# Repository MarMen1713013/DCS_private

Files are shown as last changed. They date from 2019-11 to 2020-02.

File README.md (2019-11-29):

# Estimate of an *unknown* torque and *constant reference* tracking 

## DONE
$$
I_{sens}/I_{out} = K = \textit{mean on datasheet}
$$

- [ ] Andrea: Motor parameter estimation
- [ ] Adrija: Torque estimation
- [ ] Marco: Hardware + P~~ID~~ (.ino or .m)

## Introduction

## Definition

## Goal

## Code

## Results

[TOC]

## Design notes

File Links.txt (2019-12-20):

1) Usefull Tutorial

https://howtomechatronics.com/tutorials/arduino/arduino-dc-motor-control-tutorial-l298n-pwm-h-bridge/ 

------------------------------------------------------------------------------------------------------

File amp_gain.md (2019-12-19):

# OP AMP configurations

Two choices are actually available:
1. transimpedance (low gain) + high voltage gain
2. transimpedance (high gain)

## First

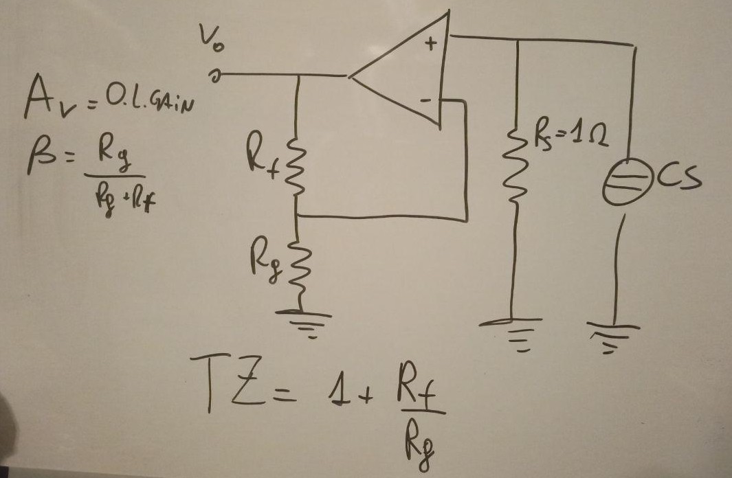
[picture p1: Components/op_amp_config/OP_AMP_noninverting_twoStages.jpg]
two_stages

$$
\left\{
\begin{align*}
V_o &= A_v*V_{in} \\
V_{in}^+ &= R_s*I_{cs} \\ 
V_{in}^- &= \frac{R_g}{R_f + R_g}*V_o
\end{align*}
\right.
$$
Setting $R_s = 1 \Omega$ we can exchange $V_{in}^+$ with $I_{cs}$, and easily solve the system.transimpedance
Or else we could see it in a __*Control fashion*__:
$$
\left\{
\begin{align*}
A_v &= \text{open loop gain} \\
\beta &= \frac{R_g}{R_f + R_g}= \text{feedback transfer function} \\
G &= R_s = \text{pre-amplifier}
\end{align*}
\right.
$$
Hence: $W_{TZ} = G \frac{A_v}{1+\beta A_v} \simeq \frac{G}{\beta} = 1+\frac{R_f}{R_g}$ is our Voltage gain.

## Second

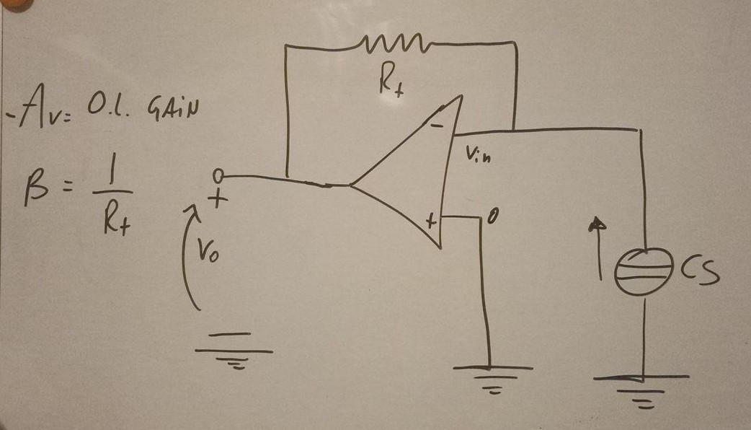
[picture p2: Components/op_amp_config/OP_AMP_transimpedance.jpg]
transimpedance

$$
\left\{
\begin{align*}
V_{in}^+ &= 0 \\
V_{in}^- &= V_{in} =V_o + R_sI_{cs} \\
V_o &= -A_vV_{in}
\end{align*}
\right.
$$
It could be solved easily or else, as before, we could see it in a __*Control fashion*__:
$$
\left\{
\begin{align*}
-A_v &= \text{open loop gain} \\
\beta &= \frac{1}{R_f}= \text{feedback transfer function}
\end{align*}
\right.
$$
Hence: $W_{TZ} = \frac{-A_v}{1-\beta A_v} = \frac{1}{\frac{1}{-A_v}+\beta}\simeq \frac{1}{\beta} = R_f$ is our Voltage gain.

### Anti Aliasing

Since an anti-aliasing is needed on the current loop, we simply implement it as low pass filter, i.e. we add a capacitor $C_f$ in parallel to the resistance $R_f$ so as the total transfer functions $\beta$ and $W_{TZ}$ are:
$$
\begin{align*}
\beta &= \frac{1}{R_f} + sC_{f}\\
W_{tz} &\simeq \frac{1}{\beta} = \frac{R_f}{1+sC_fR_f}
\end{align*}
$$
Imposing the time constant to be at $\tau = \frac{1}{1kHz} = R_fC_f$ we have $C_f$ as :
$$
C_f = \frac{1}{R_f*1kHz}
$$

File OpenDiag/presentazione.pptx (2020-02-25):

## Estimation of DC Motor Load

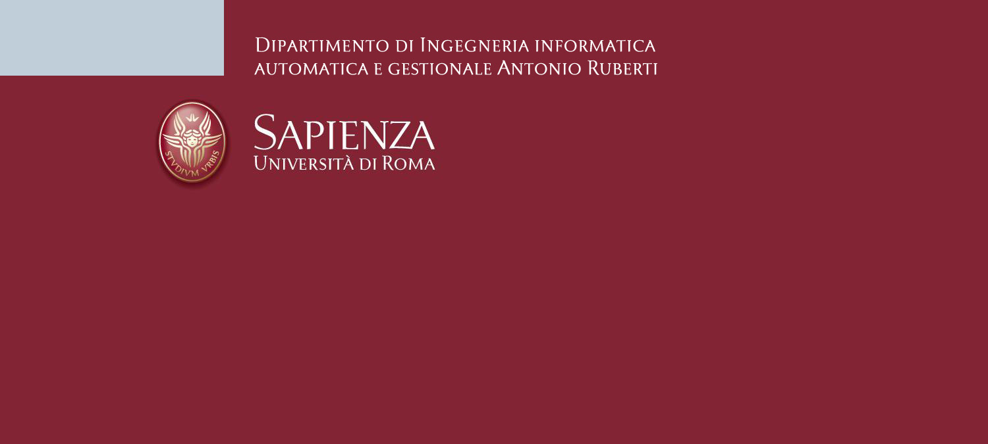
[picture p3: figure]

Project Members: Marco Menchetti, Adrija Sen, Andrea Malaguti

Guided By: Prof. Claudia Califano
Course: Digital Systems Control

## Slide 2

Estimation of DC Motor Load

Goal of the project :

- Estimation of DC Motor parameters
- Estimation of DC Motor load
- Realisation of a PI Controller

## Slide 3

HARDWARE AND SOFTWARE USED:

- Arduino Uno R3
- DC Motor (2x12V)
- H-Bridge(LM298-N)
- Hall-Effect Encoder
- Operational Amplifier(LM324N)
- Resistors()
- Potentiometer 1KΩ
- Power Supply – (12V, 2A max.)
- Matlab 2019a
- Matlab Arduino support package

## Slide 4

Arduino UNO R3

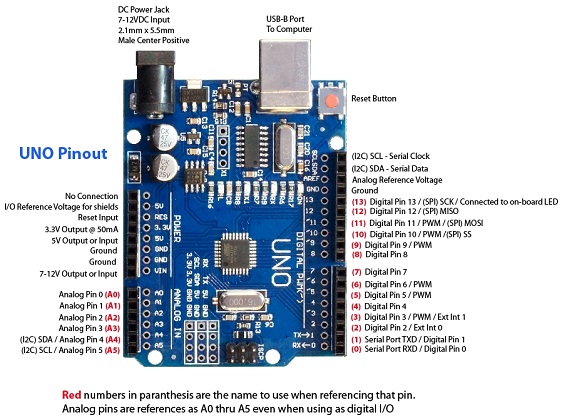
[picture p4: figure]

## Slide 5

Arduino Uno is a microcontroller board based on the ATmega328P (datasheet). It has 14 digital input/output pins (of which 6 can be used as PWM outputs), 6 analog inputs, a 16 MHz quartz crystal.

Tech Specifications of Arduino UNO R3:

Operating Voltage | 5V
Input Voltage (recommended) | 7-12V
Input Voltage (limit) | 6-20V
Digital I/O Pins | 14 (of which 6 provide PWM output)
PWM Digital I/O Pins | 6
Analog Input Pins | 6
DC Current per I/O Pin | 20 mA
DC Current for 3.3V Pin | 50 mA
Flash Memory | 32 KB (ATmega328P) of which 0.5 KB used by bootloader
SRAM | 2 KB (ATmega328P)
EEPROM | 1 KB (ATmega328P)
Clock Speed | 16 MHz
LED_BUILTIN | 13

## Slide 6

DC Motor + Encoder

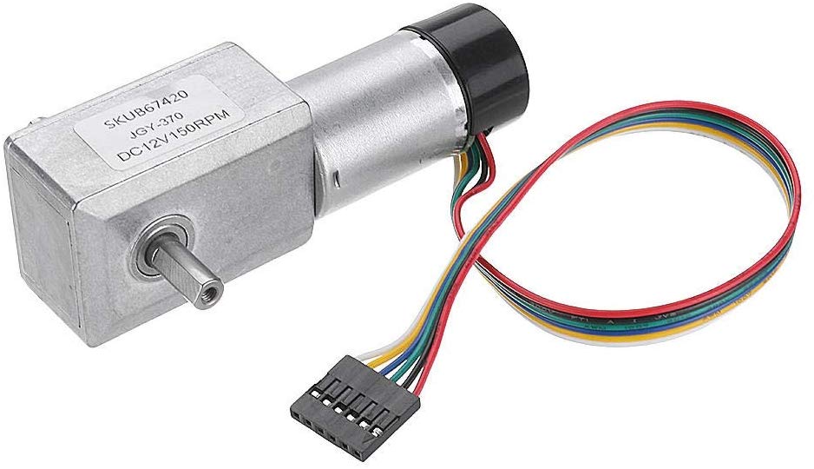
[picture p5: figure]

## TECHNICAL SPECIFICATIONS FOR ENCODER-MOTOR DUO

- Operating voltage: 6V to 18V
- Rated voltage: 12V
- Reduction ratio: 40:1
- No-load current: 40 mA
- No-load speed: 150 RPM
- Rated torque: 1.5 kg cm
- Maximum torque: 6.4 kg cm
- Stop current: 1.3 A
- Hall Incremental Encoder
- Encoder resolution: 440 CPR
- Weight: 150 g
- Red: Motor power +
- Black: Encoder GND
- Green: Encoder Phase A
- Yellow: Encoder Phase B
- Blue: Encoder power supply 5V
- White: Motor power

## LM324N (OPERATIONAL AMPLIFIER)

Slew Rate | 0.5V/µs
Gain Bandwidth Product | 1,2MHz
Current - Input Bias | 20nA
Voltage - Input Offset | 3mV
Current - Supply | 1.4mA
Current - Output / Channel | 40mA
Voltage - Supply, Single/Dual (±) | 3V ~ 32V, ±1.5V ~ 16V
Operating Temperature | 0°C ~ 70°C

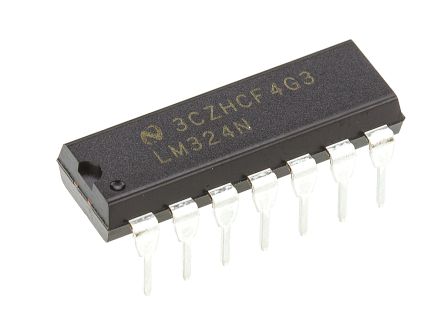
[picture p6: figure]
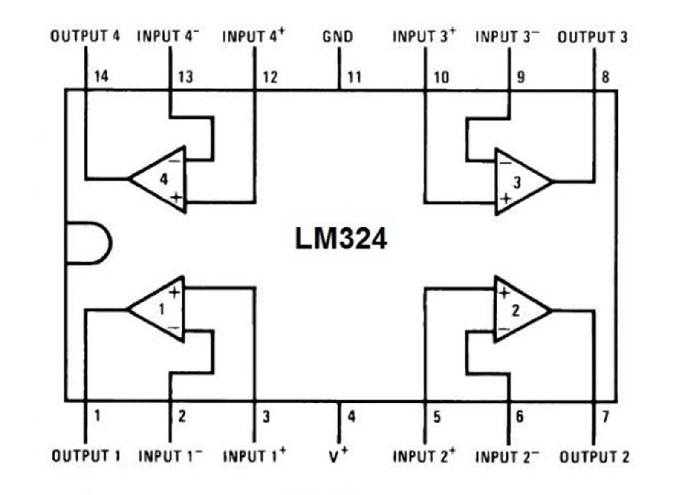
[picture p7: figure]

Pin-out for LM324N

## LM324N-NON-INVERTING AMPLIFIER

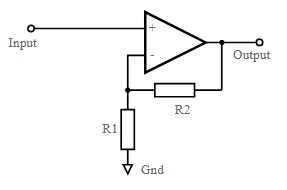
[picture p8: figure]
Non-Inverting Operational Amplifier Circuit

The gain of the non-inverting op-amp is calculated as:

We took the value of the resistors as :
R2= 1000 Ω
R1= 1000 Ω
Therefore, the gain Av= 2

## L298N (H-BRIDGE DRIVER)

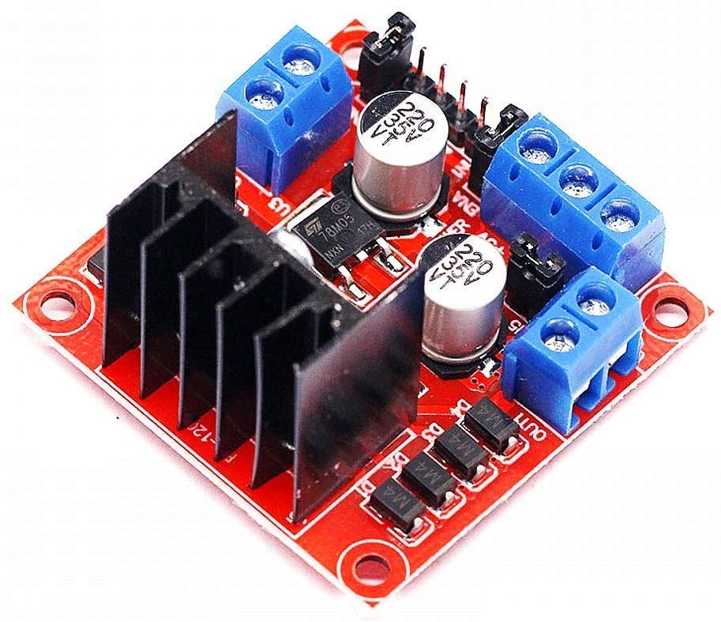
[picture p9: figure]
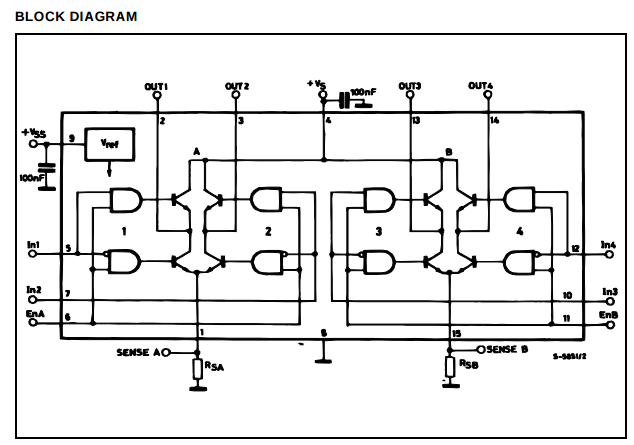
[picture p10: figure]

## L298N (TECHNICAL SPECIFICATIONS )

Technical
Bandwidth | 1 MHz
Common Mode Rejection Ratio | 70 dB
Dual Supply Voltage | 9 V
Gain | 100 dB
Gain Bandwidth Product | 1.3 MHz
Input Bias Current | 150 nA
Input Offset Voltage (Vos) | 7 mV
Max Dual Supply Voltage | 15 V
Max Operating Temperature | 70 °C
Max Supply Voltage | 30 V
Min Dual Supply Voltage | 1.5 V
Min Operating Temperature | 0 °C
Min Supply Voltage | 3 V
Nominal Supply Current | 1.2 mA
Number of Amplifiers | 4
Number of Channels | 4
Number of Circuits | 4
Number of Elements | 4
Operating Supply Current | 1.5 mA
Operating Supply Voltage | 15 V
Output Current | 70 mA
Output Current per Channel | 70 mA
Slew Rate | 0.4 V/µs
Voltage Gain | 100 dB

## PULSE WIDTH MODULATION

Pulse Width Modulation(PWM) allows us to vary how much time the signal is high in an analog fashion. While the signal can only be high (usually 5V) or low (ground) at any time, we can change the proportion of time the signal is high compared to when it is low over a consistent time interval.

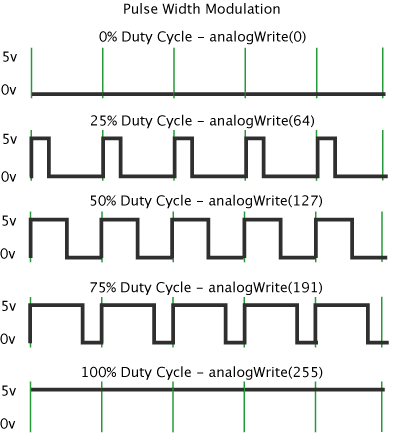
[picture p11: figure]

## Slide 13

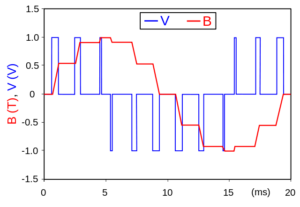
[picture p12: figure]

Sample output of PWM modulated signal

Duty Cycle is given by:

d= (t_(on))/(t_(on) +t_(off))

Type equation here.

## INCREMENTAL ENCODERS

An incremental encoder generates a pulse for each incremental step in it's rotation. The most common type of incremental encoder uses two output channels (A and B) to sense position. Using two code tracks with sectors positioned 90° out of phase, the two output channels of the quadrature encoder indicate both position and direction of rotation. If A leads B, for example, the disk is rotating in a clockwise direction else vice versa.

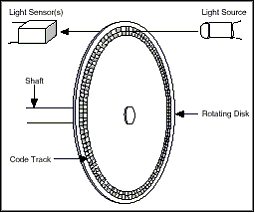
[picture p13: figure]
principles of an optical incremental encoder for position measurement

## Motor Parameters Estimation

J(dω)/(dt)+Bω=T−T_L
V_s =E_(emf) −R_a i_a

Since,

ω: rated speed
J: motor inertia
B: friction
Ra: armature resistance
ia: armature current
Eemf: back-ElectroMotiveForce

E_(emf) =K_e ω

V_s =K_e ω−R_a i_a

Therefore,

K_e =(V_s −R_a i_a)/ω

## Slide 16

Where, Vs= 12 V
ia = 40 mA (rated)
Ra= 13.7 Ω (estimated)
ω = 150 RPM = 15,7 rad/s

Back-EMF constant and Torque constant have the same numerical value for DC motors:

K_e [V/(rad/s)]=K_T [(Nm)/A]

So,
K_T =0.729[(Nm)/A]

&

K_e =0.729[V/(rad/s)]

## MECHANICAL TIME CONSTANT ESTIMATION

Mechanical time constant:
Time needed by the angular velocity to reach 63% of final value.

τ_(mech) =30ms

Now using, τ_(mech) = (R_(aJ))/(K_e K_T) [ms]

J=(K_e K_T τ_(mech))/(R_a)[kg/m^2 ]

Gives us,

J=13.4x 10^(−2) [kg/m^2 ]

## LOAD TORQUE ESTIMATION

J(dω)/(dt)+Bω=T−T_L
V_s =E_(emf) −R_a i_a

Inserting B=0, we get,
J(dω)/(dt)=T−T_L

Also at steady state, J(dω)/(dt) =0. Therefore, T−T_L =0.

This gives, T=T_L .

We know , T =K_T i_a

Torque-Current relationship

## MATLAB CODES FOR PI-CONTROLLER

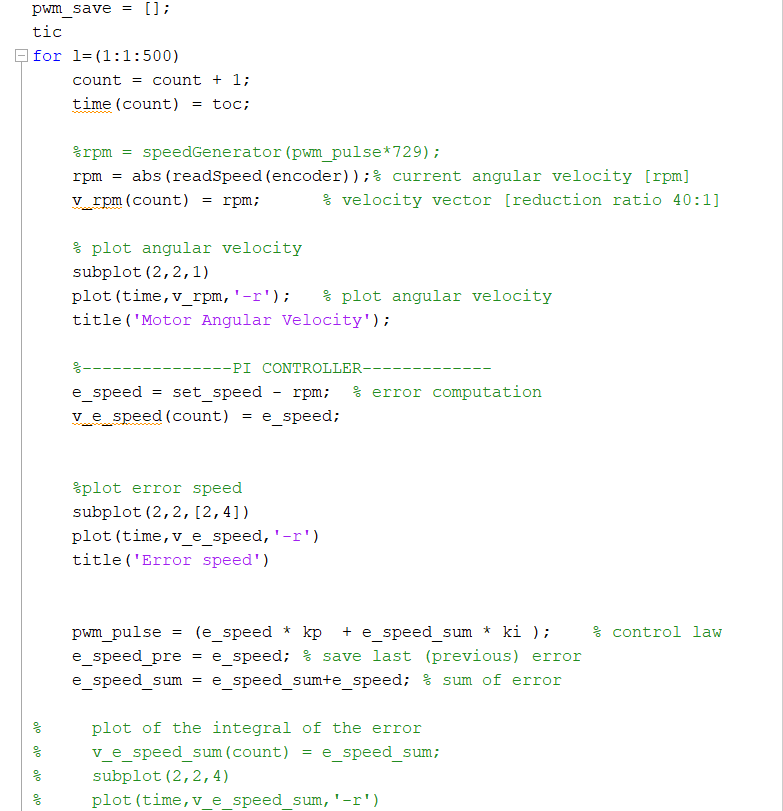
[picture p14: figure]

## MATLAB CODES FOR PI-CONTROLLER(CONTD.)

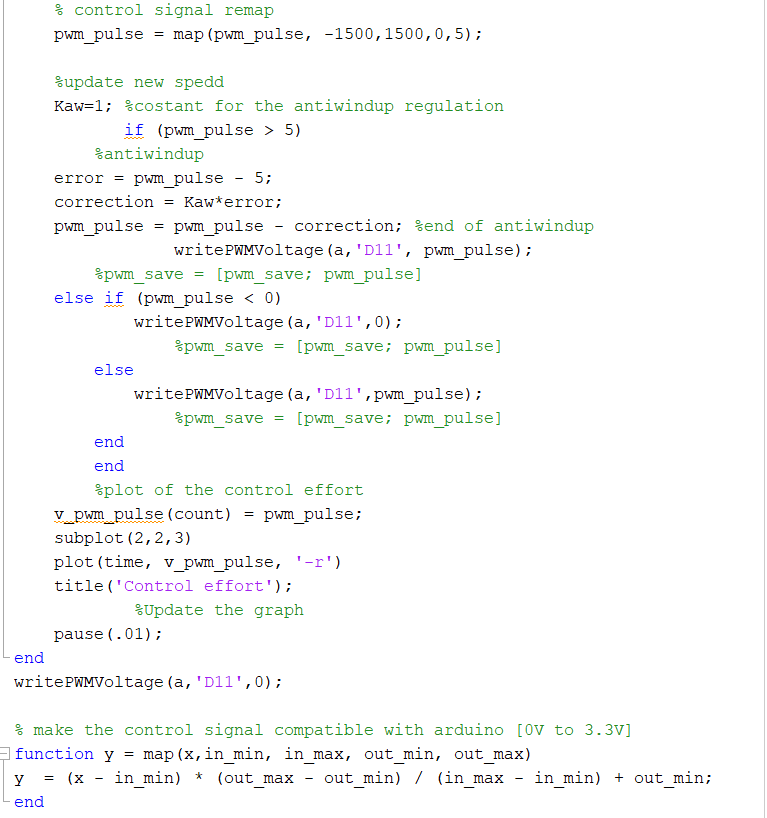
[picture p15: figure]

## CONCLUSIONS

During the development of this project we have learnt the following:
- Learned how to interface Arduino and Matlab for real time
simulation and analysis
- Estimated the DC motor parameters in order to obtain an estimate
of the motor torque
- Implemented a PI speed controller and seen the effects of the
proportional and integral gains.
Future work: possibly, an implementation of a position controller
introducing external sensors to create a zero reference signal
(mechanical or magnetic switch).

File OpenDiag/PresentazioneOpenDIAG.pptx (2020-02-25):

## Control Engineering

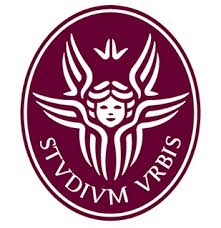
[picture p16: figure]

Sapienza Università di Roma

Adrija Sen
Andrea Malaguti
Marco Menchetti

## Cos’è l’ingegneria automatica?

Modellazione

Controllo

Simulazione

SISTEMA

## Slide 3

SISTEMA

Processo Industriale

Robotica

Processo Chimico

Smart Grids

Meccatronica

## Un Ingegnere Multitasking

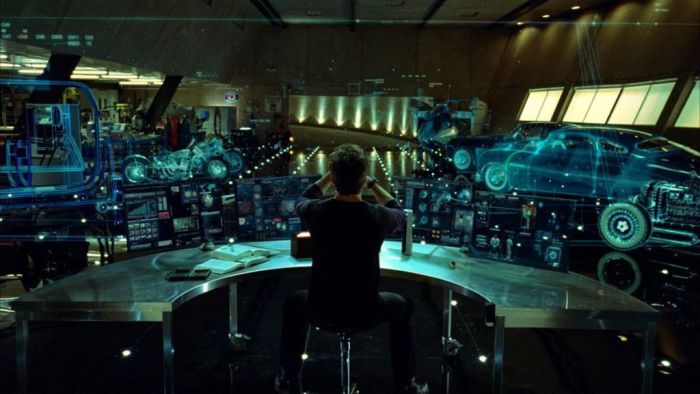
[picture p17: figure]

## Applicazioni Meccatroniche dell’ingegneria

Il nostro obiettivo è quello di controllare la velocità di un motore con carico variabile.
Molto più semplicemente vogliamo che il motore si muova ad una velocità da noi stabilita. Il circuito aumenterà in modo automatico la potenza del motore quando noi cercheremo di fermarlo in modo da mantenere la velocità desiderata.

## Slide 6

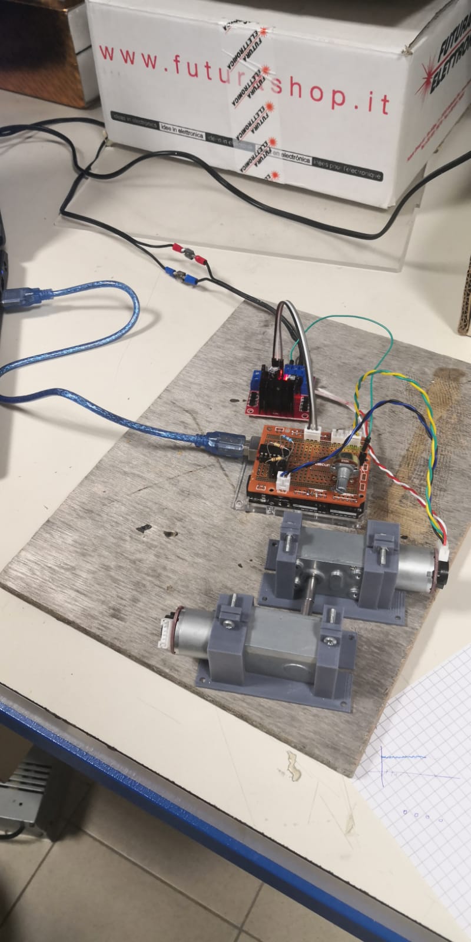
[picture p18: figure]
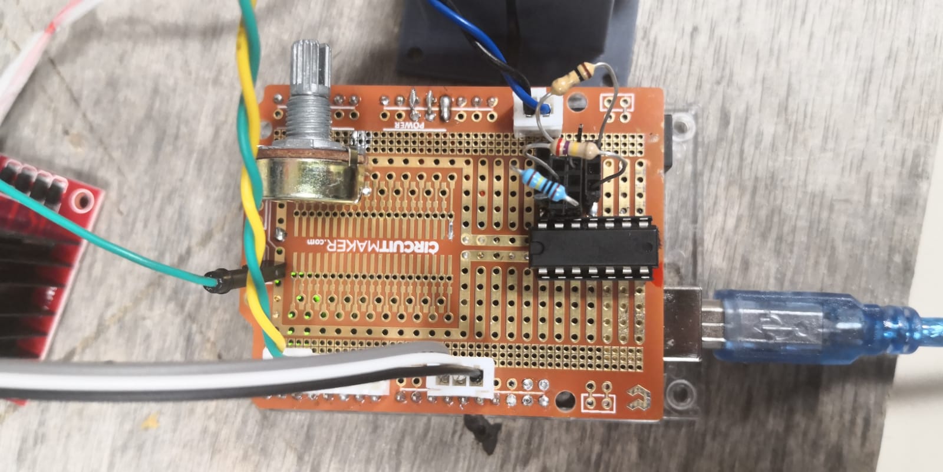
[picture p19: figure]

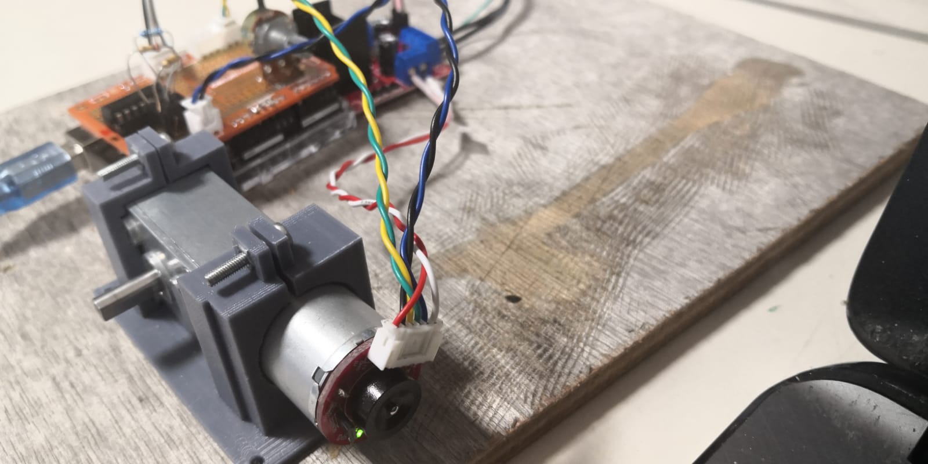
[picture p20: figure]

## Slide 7

Attuatore

Controllore

Sensori

## PID: il controllore più usato nelle applicazioni industriali

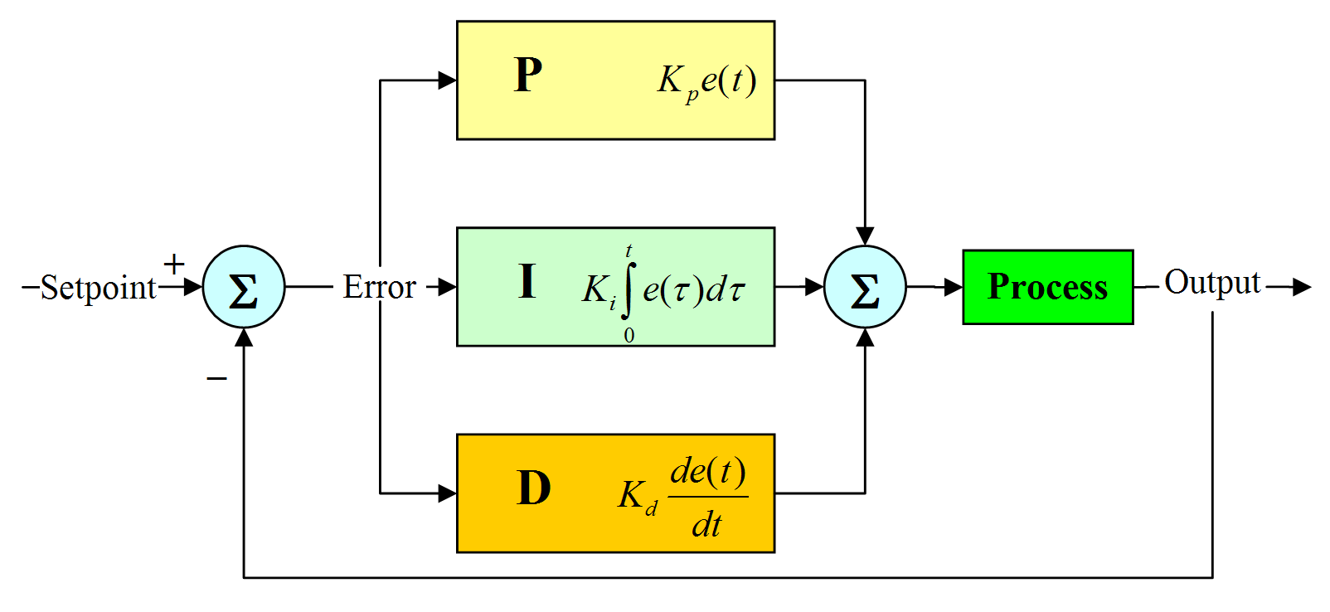
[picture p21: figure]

## La retroazione (feedback)

- Applicazioni Ingegneristiche

- Misura
- Valuta
- Correggi

## La retroazione (feedback)

- Applicazioni Ingegneristiche
- Social media
- Politica

- Misura
- Valuta
- Correggi

## Il motore: matematica dietro la fisica

1. Controllo
2. Carico
3. ???

1.

2.

3.

3.

## Il motore: matematica dietro la fisica

1. Controllo
2. Carico
3. Inerzia
4. Attrito

1.

2.

3.

4.

## Il motore: matematica dietro la fisica

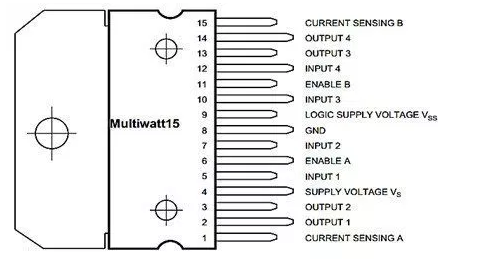
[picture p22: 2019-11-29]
Components/L298_pinout.png

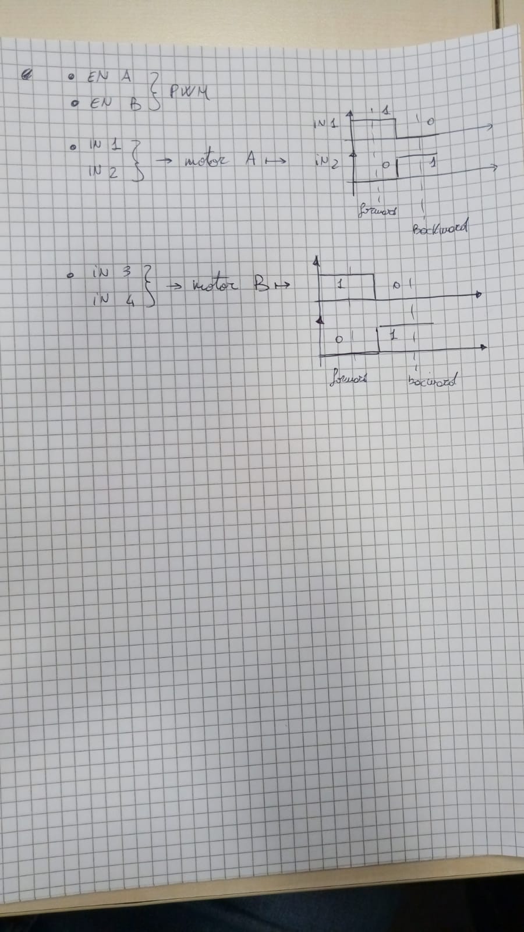
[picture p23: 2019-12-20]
Components/MotorsPinout.jpg

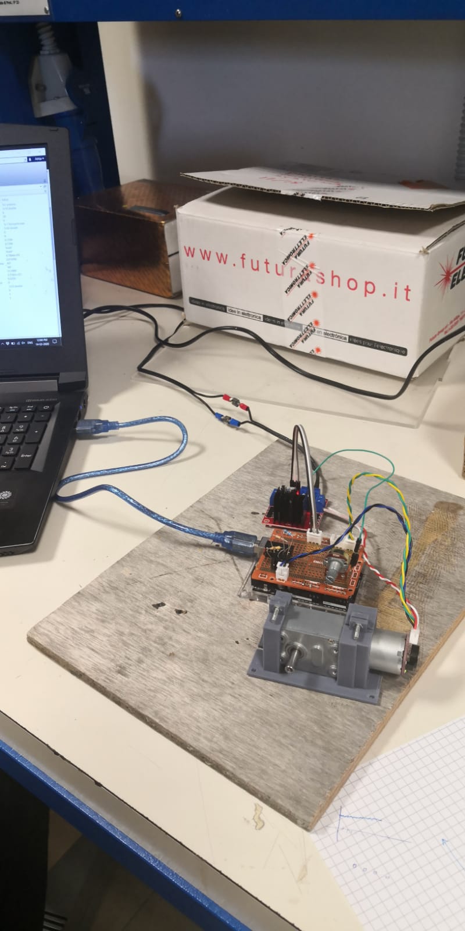
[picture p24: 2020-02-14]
OpenDiag/circuit.jpg

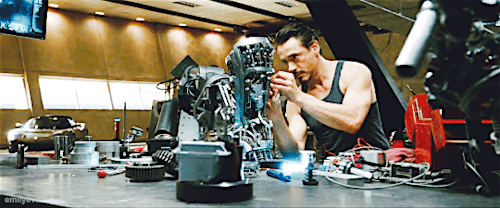
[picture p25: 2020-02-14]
OpenDiag/tumblr_pael7m89ay1vsj8fmo3_500.webp

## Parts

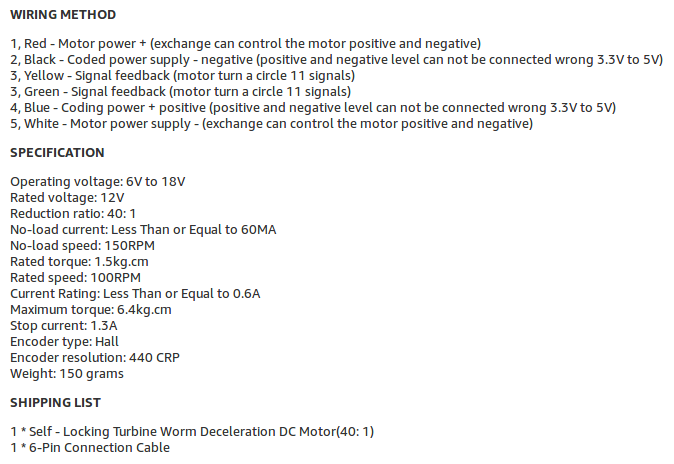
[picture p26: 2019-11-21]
Components/Datasheet/motor_details.png

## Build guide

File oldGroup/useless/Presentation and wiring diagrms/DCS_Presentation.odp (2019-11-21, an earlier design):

## Estimation of DC motor load


Team: Alessia De Matteis, Andrea Guidi, Manuel Donsante

Course: Digital Control Systems

Academic Year: 2017/2018

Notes: <number>

## Objectives

- Estimation of DC motor parameters
- Estimation of DC motor load
- Design of a PI speed regulator

Estimation of DC motor load

2/27/18

Page 2

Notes: <number>

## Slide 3

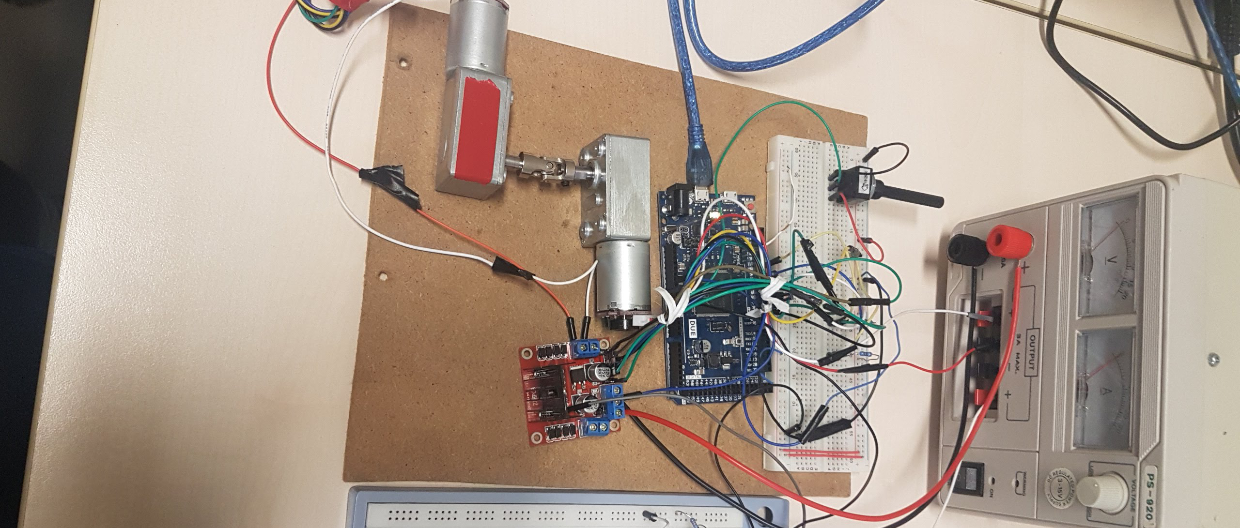
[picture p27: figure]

Estimation of DC motor load

2/27/18

Page 3

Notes: <number>

## Hardware and software

- Arduino Due (ARM Cortex-M3 CPU)
- 2x 12V DC Motor
- Hall Effect Encoder
- H-bridge: L298-N
- Operational Amplifier: LM324N
- 1KΩ Potentiometer
- Resistors: 2x 12KΩ, 2x 33KΩ, 1x 1Ω
- 12 V Power Supply – 20 A max
- MATLAB 2017b
- MATLAB Arduino support package
- Fritzing

Estimation of DC motor load

2/27/18

Page 4

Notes: <number>

## Hardware: Arduino Due

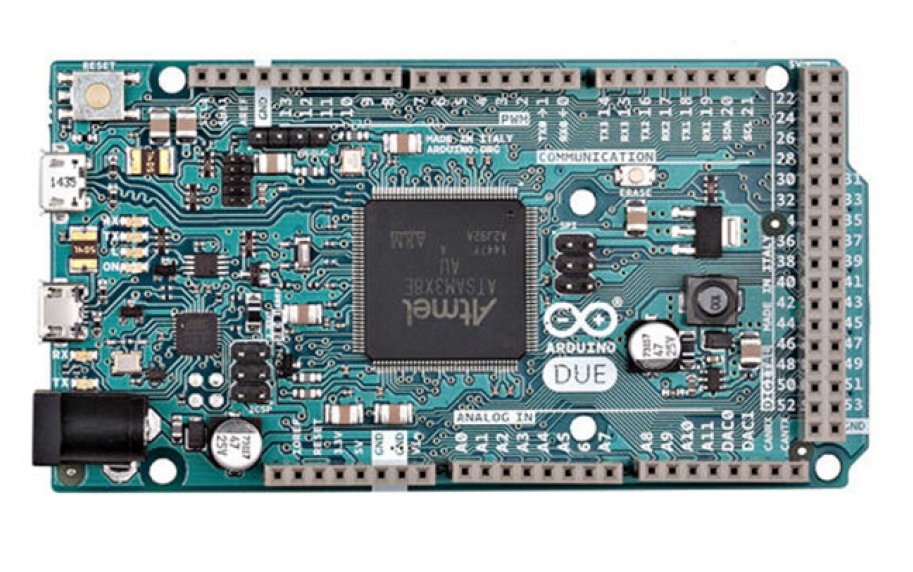
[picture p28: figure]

The Arduino Due is a microcontroller board based on the

Atmel SAM3X8E ARM Cortex-M3CPU.

It has 54 digital input/output pins (of which 12 can be used as PWM outputs) and 12 analog inputs.

Used to drive the motor by the H-bridge, to read the voltage from the potentiometer and to read the digital signal from the encoder.

Estimation of DC motor load

2/27/18

Page 5

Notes: <number>

## Hardware: DC Motors + Encoders

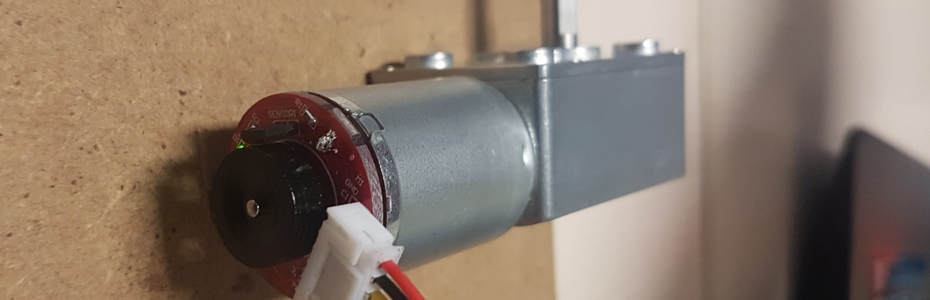
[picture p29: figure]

- Operating voltage: 6V to 18V
- Rated voltage: 12V
- Reduction ratio: 40:1
- No-load current: 40 mA
- No-load speed: 150 RPM
- Rated torque: 1.5 kg cm
- Maximum torque: 6.4 kg cm
- Stop current: 1.3 A
- Hall Incremental Encoder
- Encoder resolution: 440 CPR
- Weight: 150 g
- Red: Motor power +
- Black: Encoder GND
- Green: Encoder Phase A
- Yellow: Encoder Phase B
- Blue: Encoder power supply 5V
- White: Motor power -

Estimation of DC motor load

2/27/18

Page 6

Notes: <number>

## Incremental Encoders

- Incremental encoders can measure relative displacements starting from an arbitrary position.
- They use two digital outputs, A and B phases, set in quadrature.
  B phase is commonly used for detecting sense of rotation.
- MCUs generally use software interrupts for phase detection and counters to measure increments in position.

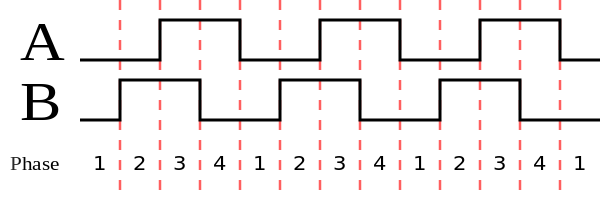
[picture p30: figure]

Estimation of DC motor load

2/27/18

Page 7

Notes: <number>

## Hardware: L298-N and LM324N

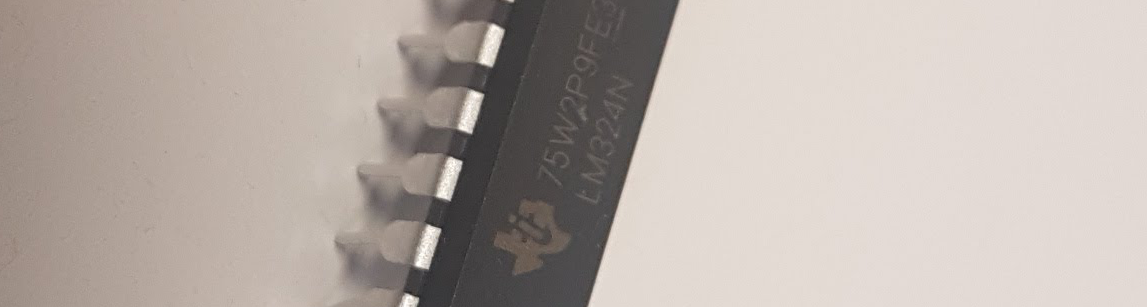
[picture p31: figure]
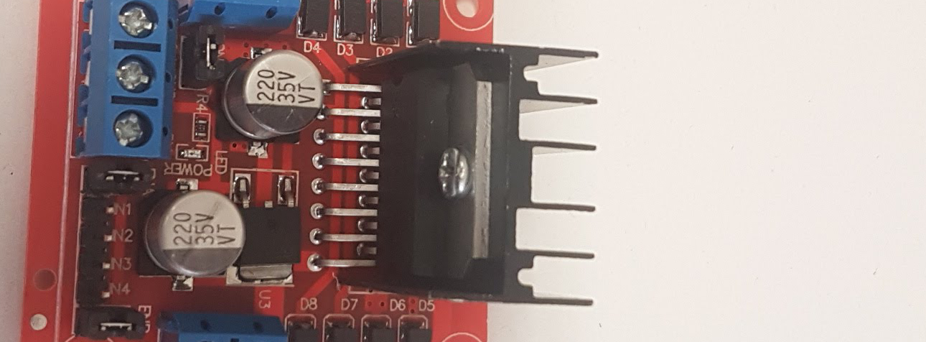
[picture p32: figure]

The L298-N

- Is a dual full-bridge driver capable of driving inductive loads such as motors
- Can supply up to 2A per motor.
- Has logic pins to allow to enable or disable motors (or speed regulation with PWM)
- A pin for the connection of an external sensing resistor is available; (for this purpose,
  a 1Ω resistor was connected to this pin)

The LM324N

- Is a quad operational amplifier used for example as a DC gain block (as in our case).
- Can operate from a single supply over a wide range of voltages.
- It was used to amplify the voltage signal from the current sensing resistor on L298-N.

Estimation of DC motor load

2/27/18

Page 8

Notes: <number>

## PWM (Pulse Width Modulation)

- Pulse Width Modulation (PWM) is a technique of modulation of a digital signal.
- It is based on generating a square wave with fixed frequency but variable duty cycle d.
- It can be used to drive power systems without affecting performances (such as DC motors).

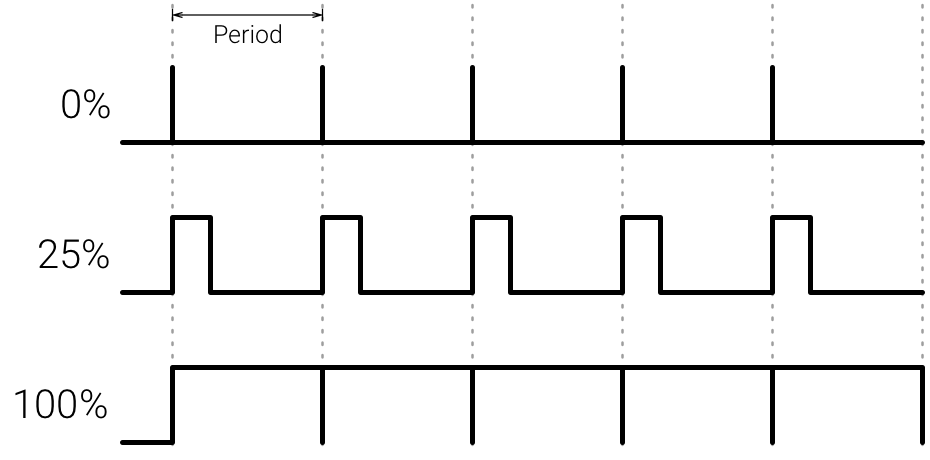
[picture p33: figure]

Estimation of DC motor load

Duty cycle:

Page 9

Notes: <number>

## Non-inverting Amplifier LM324N

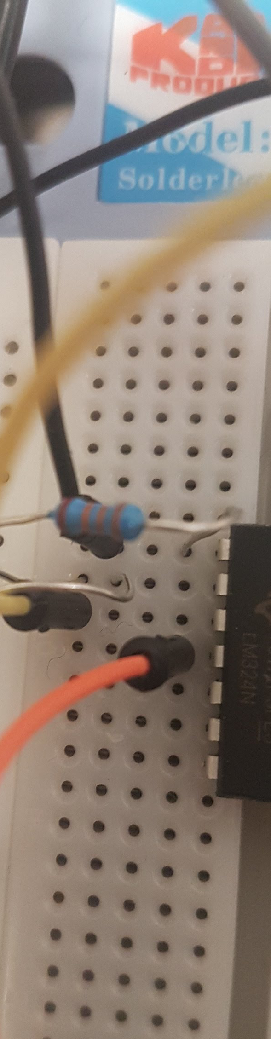
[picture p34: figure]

Estimation of DC motor load

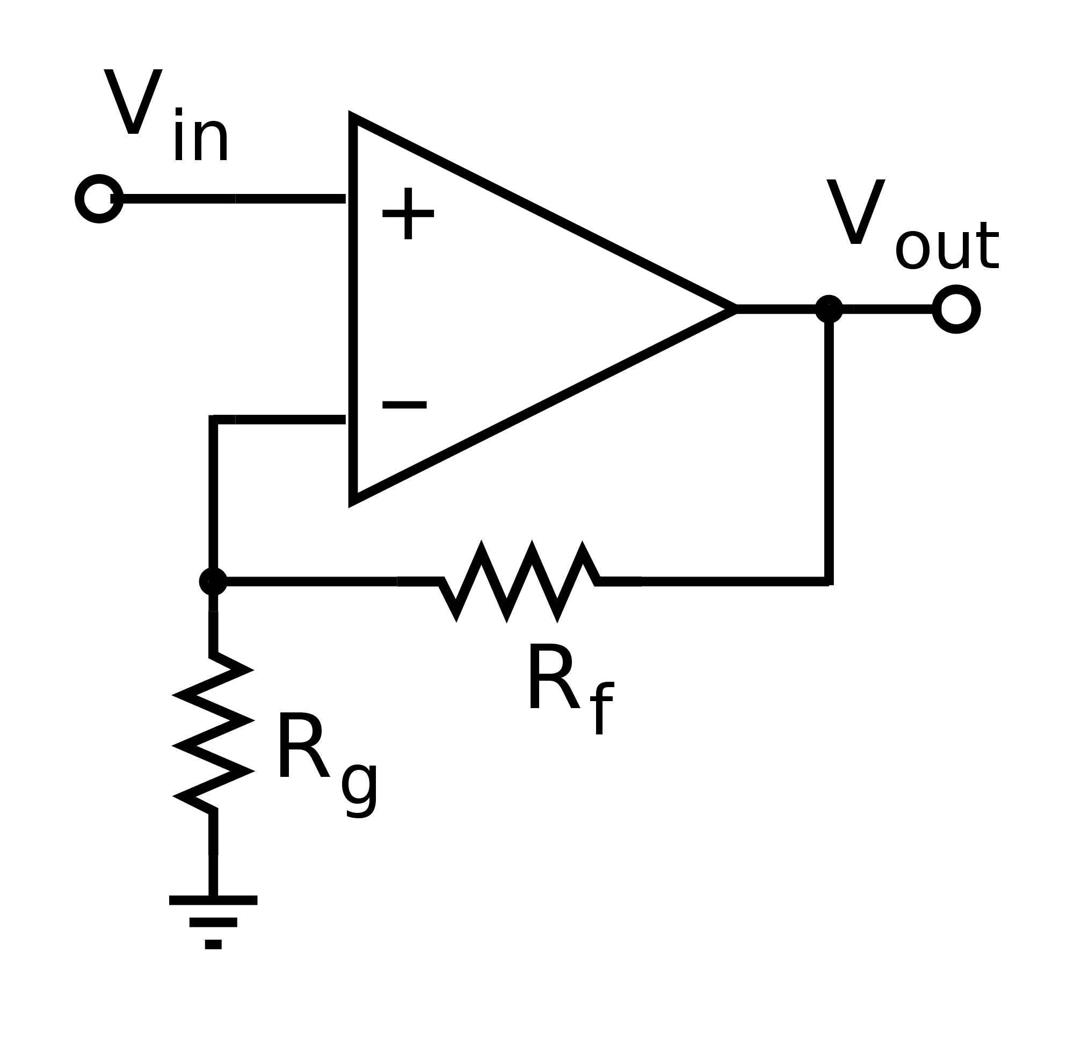
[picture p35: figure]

Rf = Rg = 33 KΩ have been chosen in such a way that G=2.

Page 10

2/27/18

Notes: <number>

## Wiring diagram

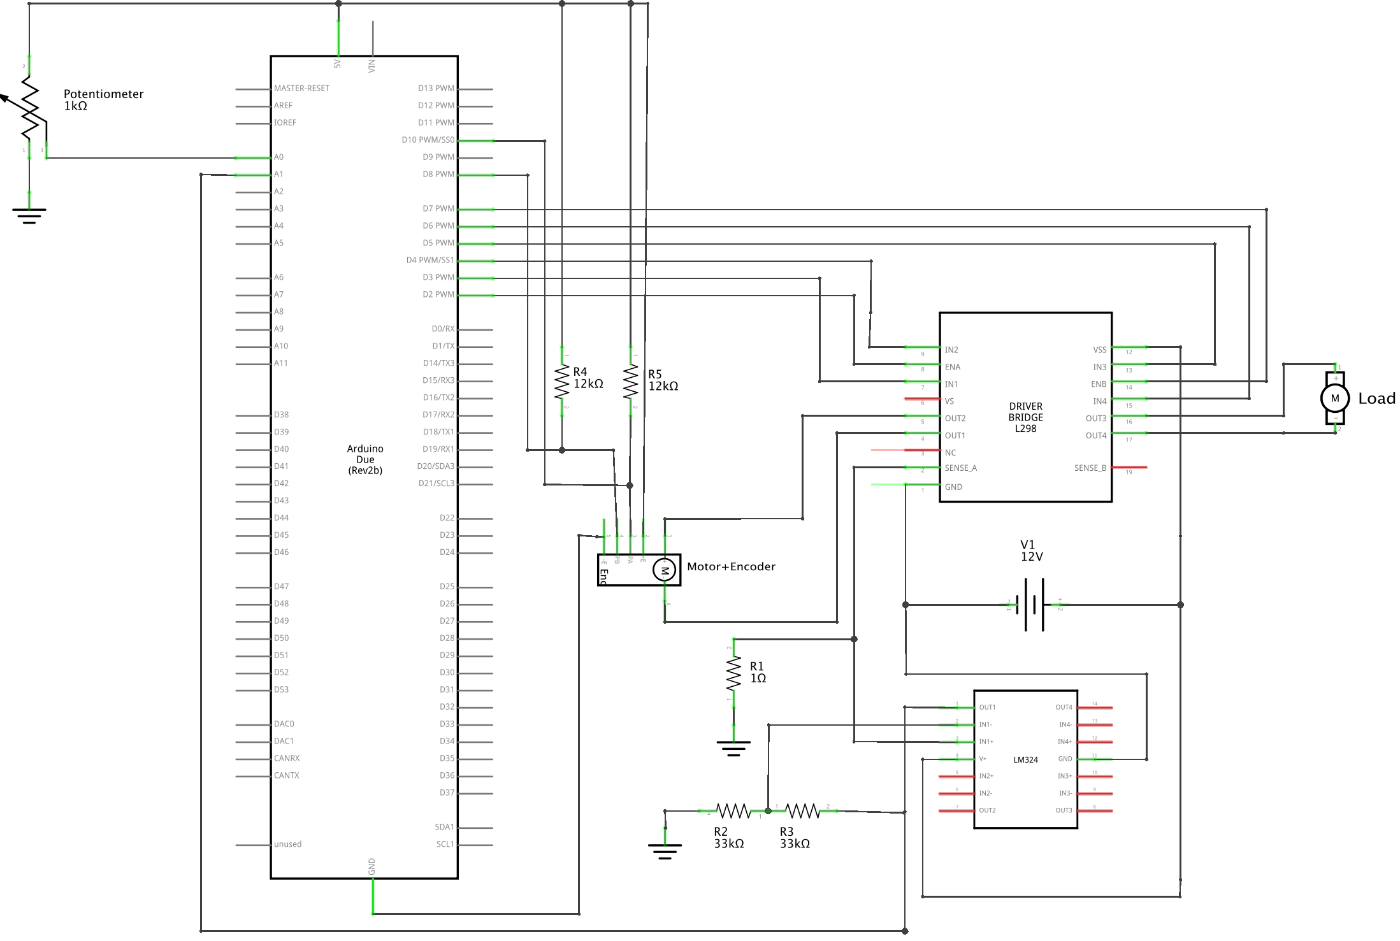
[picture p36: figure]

Estimation of DC motor load

2/27/18

Page 11

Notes: <number>

## Motor parameters estimation

Motor dynamical equations:

ω, rated speed

J, motor inertia

B, friction

Ra, armature resistance

ia, armature current

Eemf, back-ElectroMotiveForce

Back-EMF constant:

Estimation of DC motor load

2/27/18

Page <number>

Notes: <number>

## Motor parameters estimation

Where Vs= 12 V

ia = 40 mA (rated)

Ra= 13.7 Ω (estimated)

ω = 150 RPM = 15,7 rad/s

Back-EMF constant and Torque constant have the same numerical value for DC motors:

So,

Estimation of DC motor load

2/27/18

Page 13

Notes: <number>

## Mechanical time constant estimation

Using:

Mechanical time constant:

Time needed by the angular velocity

to reach 63% of final value.

We can compute motor inertia:

Estimation of DC motor load

2/27/18

Page 14

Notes: <number>

## Load torque estimation

Motor dynamical equations:

Neglecting friction:

At steady state:

We finally know that:

Estimation of DC motor load

Torque – current relationship

Page 15

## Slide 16

Matlab code: Motor Load Estimation

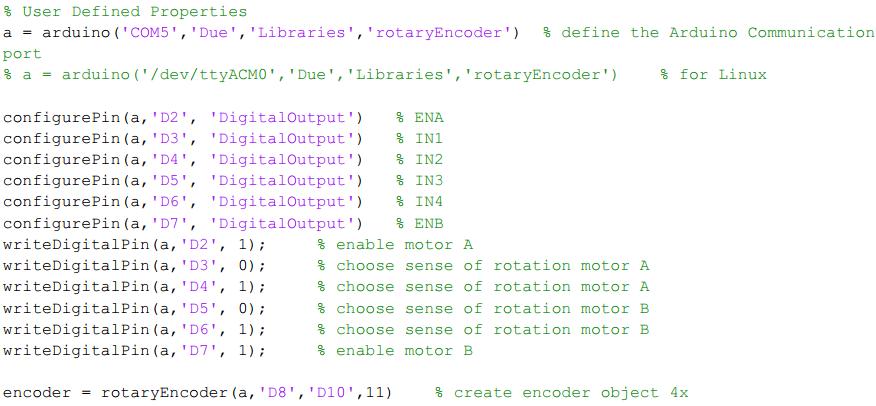
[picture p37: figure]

Estimation of DC motor load

2/27/18

Page 16

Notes: <number>

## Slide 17

Matlab code: Motor Load Estimation

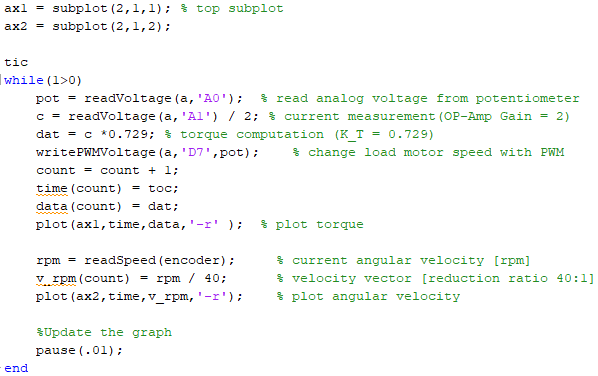
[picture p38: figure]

Estimation of DC motor load

2/27/18

Page 17

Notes: <number>

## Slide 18

Motor Load estimation: a video

Estimation of DC motor load

2/27/18

Page 18

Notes: <number>

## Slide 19

Matlab code: P/PI Speed Controller

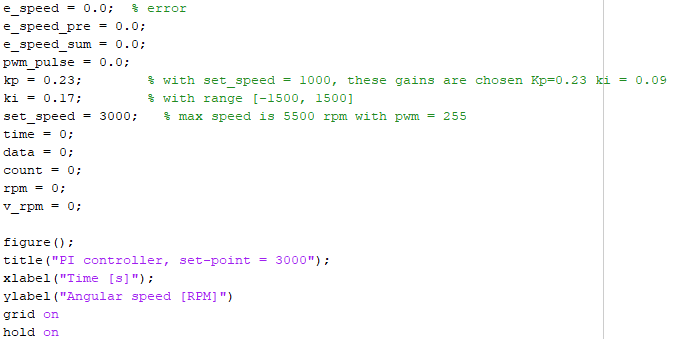
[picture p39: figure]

Estimation of DC motor load

2/27/18

Page 19

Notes: <number>

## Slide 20

Matlab code: P/PI Speed Controller

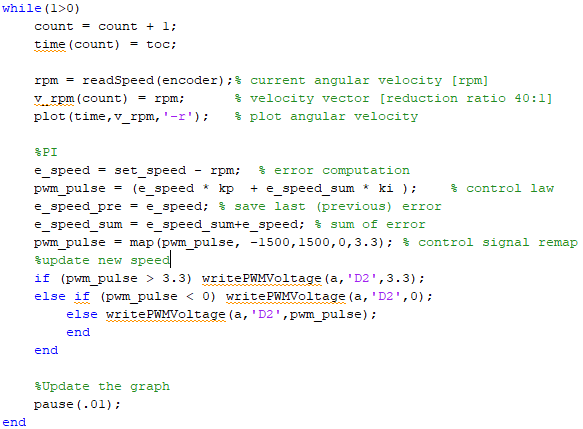
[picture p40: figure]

Estimation of DC motor load

2/27/18

Page 20

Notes: <number>

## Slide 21

Simulation: P vs PI Controller

Estimation of DC motor load

2/27/18

Page 21

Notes: <number>

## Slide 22

PI controller: a video

Estimation of DC motor load

Page 22

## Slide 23

Conclusions

During the development of this project we have:

- Learned how to interface Arduino and Matlab for real time simulation and analysis;
- Estimated the DC motor parameters in order to obtain an estimate of the motor torque;
- Implemented a PI speed controller and seen the effects of the proportional and integral gains.

Future work: possibly, an implementation of a position controller introducing external sensors to create a zero reference signal (mechanical or magnetic switch).

Estimation of DC motor load

2/27/18

Page 23

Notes: <number>

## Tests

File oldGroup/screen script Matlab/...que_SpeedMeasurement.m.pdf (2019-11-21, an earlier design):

2/9/18 2:42 PM | C:\Users\m...\LoadTorque_SpeedMeasurement.m | 1 of 2

clear
clc
close all

% User Defined Properties
a = arduino('COM5','Due','Libraries','rotaryEncoder') % define the Arduino Communication port
% a = arduino('/dev/ttyACM0','Due','Libraries','rotaryEncoder') | % for Linux
configurePin(a,'D2', 'DigitalOutput') | % ENA
configurePin(a,'D3', 'DigitalOutput') | % IN1
configurePin(a,'D4', 'DigitalOutput') | % IN2
configurePin(a,'D5', 'DigitalOutput') | % IN3
configurePin(a,'D6', 'DigitalOutput') | % IN4
configurePin(a,'D7', 'DigitalOutput') | % ENB
writeDigitalPin(a,'D2', 1); | % enable motor A
writeDigitalPin(a,'D3', 0); | % choose sense of rotation motor A
writeDigitalPin(a,'D4', 1); | % choose sense of rotation motor A
writeDigitalPin(a,'D5', 0); | % choose sense of rotation motor B
writeDigitalPin(a,'D6', 1); | % choose sense of rotation motor B
writeDigitalPin(a,'D7', 1); | % enable motor B
encoder = rotaryEncoder(a,'D8','D10',11) | % create encoder object 4x

time = 0;
data = 0;
count = 0;
rpm = 0;
v_rpm = 0;

ax1 = subplot(2,1,1); % top subplot ax2 = subplot(2,1,2);

tic
while(1>0)
pot = readVoltage(a,'A0'); % read analog voltage from potentiometer c = readVoltage(a,'A1') / 2; % current measurement(OP-Amp Gain = 2) dat = c *0.729; % torque computation (K_T = 0.729) writePWMVoltage(a,'D7',pot); % change load motor speed with PWM count = count + 1;
time(count) = toc;
data(count) = dat;
plot(ax1,time,data,'-r' ); | % plot torque
rpm = readSpeed(encoder); | % current angular velocity [rpm]
v_rpm(count) = rpm / 40; | % velocity vector [reduction ratio 40:1]
plot(ax2,time,v_rpm,'-r'); | % plot angular velocity

%Update the graph
pause(.1);
end

2/9/18 2:42 PM | C:\Users\m...\LoadTorque_SpeedMeasurement.m | 2 of 2

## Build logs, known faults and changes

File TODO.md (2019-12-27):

# TODO

- [x] Dynamics of the __*sensing pin*__ on the DC/DC converter $\rightarrow$ $+/- 10 mA$ 
1. - [x] Trans-impedance gain of the amplifier: $TZ = 250 \Omega \simeq 220 \Omega$
2. - [x] low pass filter @ 1kHz $\rightarrow \tau = RC = \frac{1}{1kHz} \rightarrow C \simeq 4.7 \eta F$ 
3. - [x] if PWM frequency is high $\rightarrow$ we can push low pass frequency up to a decade before it. (C.A 100kHz) $\rightarrow \tau = \frac{1}{4kHz}$ is fine, hence $C \simeq 1nF$ 
- [x] What is it sensing? $\rightarrow$ current proportional to the one on the motor ( $I = KI_c,\text{ } K \simeq 7017$ )
> needed to optimize the *GAIN* of the amplifier

- [x] Block scheme
- [ ] Observers
- [ ] Supports
1. - [x] Motor
2. - [ ] DC/DC converter
- [x] Shield
- [x] How to use the potentiometer on loading motor
- [x] How to use the 2 pins on the H-bridge to control each motor (i.e. CW & CCW or abs. value & direction)
1. ENA, ENB are for PWM
2. IN1, IN2 (motor A) & IN3, IN4 (motor B) are for direction (i.e. 1 HIGH and 2 LOW $\rightarrow$ forward , 1 LOW and 2 HIGH $\rightarrow$ backward. Same for motor B)

## Hardware and tests

1. - [x] Try the H-bridge at max speed
2. - [x] Try the PWM with a certain profile
3. - [ ] Test dynamics of $I_{cs}$ (Try if $R_f = 220 \Omega$ is right)
4. - [ ] Test cut frequency for the low-pass filter

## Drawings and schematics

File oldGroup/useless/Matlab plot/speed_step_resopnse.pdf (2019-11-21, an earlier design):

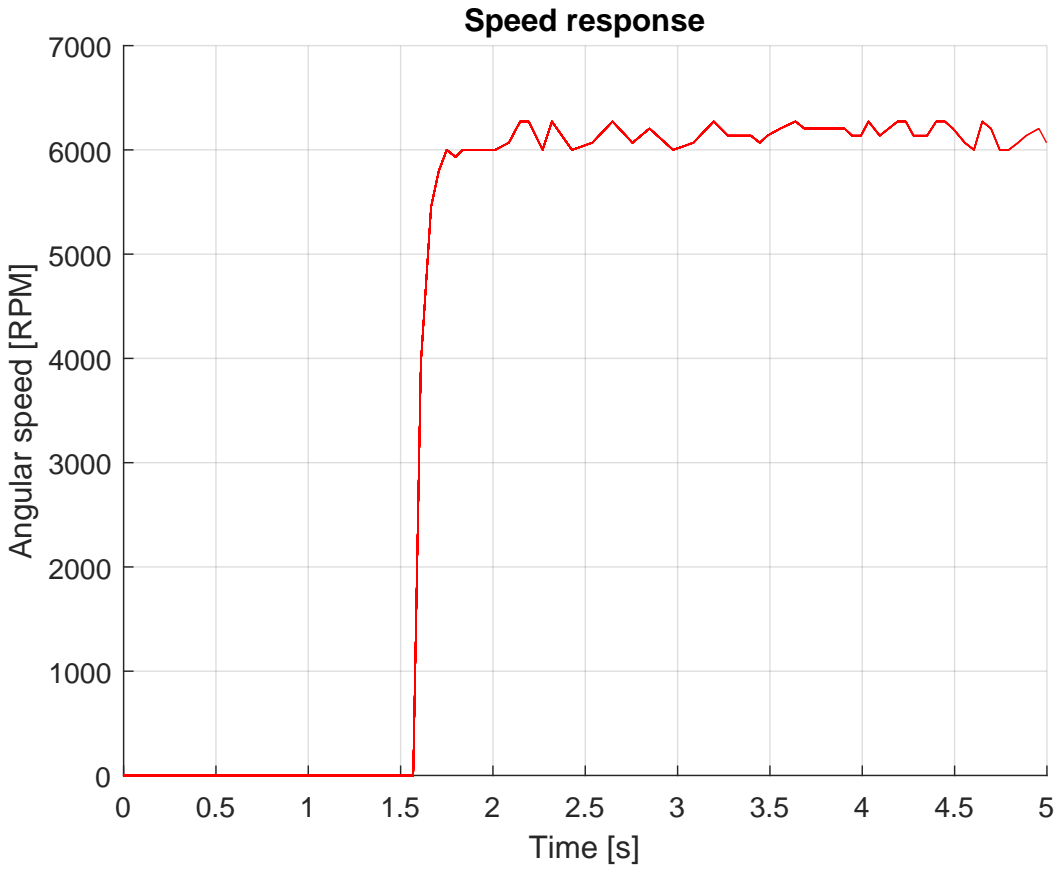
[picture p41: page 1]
Time [s]; Speed response

Angular speed [RPM]

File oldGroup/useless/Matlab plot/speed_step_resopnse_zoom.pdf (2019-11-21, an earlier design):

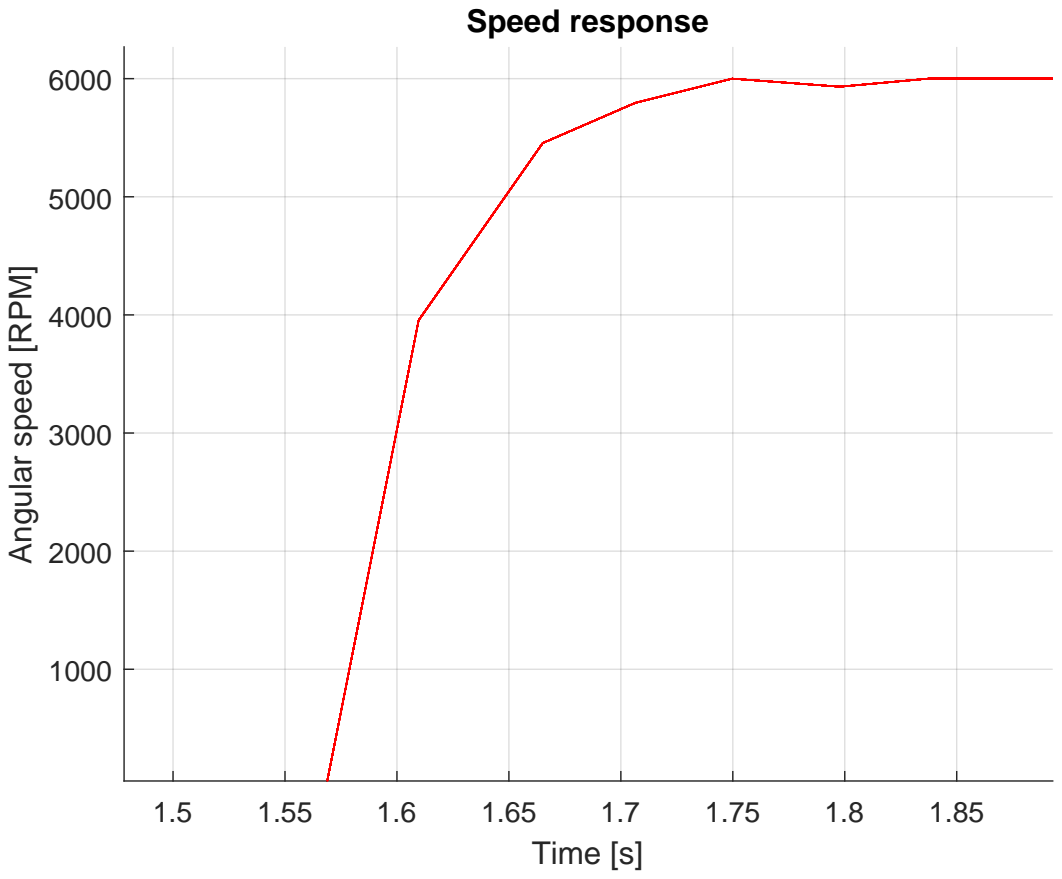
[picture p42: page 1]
Time [s]; Speed response

Angular speed [RPM]

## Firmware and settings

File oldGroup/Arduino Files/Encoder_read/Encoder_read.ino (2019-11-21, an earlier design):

#define encoder0PinA  8
#define encoder0PinB  10

volatile long encoder49Pos = 0;

long newposition;
long oldposition = 0;
unsigned long newtime;
unsigned long oldtime = 0;
double velocity;
double newangle;
double oldangle;
double vel_degrees;
long vel;
double omega;

void setup() {
  pinMode(encoder0PinA, INPUT);
  digitalWrite(encoder0PinA, HIGH);       // turn on pullup resistor
  pinMode(encoder0PinB, INPUT);
  digitalWrite(encoder0PinB, HIGH);       // turn on pullup resistor

  //pinMode(trimmer, INPUT); //input in quanto legge il valore analogico del pin A0
  pinMode(2, OUTPUT);
  pinMode(3, OUTPUT); //output perche' definisce lo stato logico del pin IN1 del modulo L298N
  pinMode(4, OUTPUT); //output perche' definisce lo stato logico del pin IN2 del modulo L298N
  //pullUP sensore pinAcceleratore
  digitalWrite(2, HIGH);   //motore con encoder
  digitalWrite(3, HIGH);
  digitalWrite(4, LOW);



  attachInterrupt(8, doEncoder, RISING);  // encoDER ON PIN 2

  Serial.begin (115200);
  Serial.println("start");                // a personal quirk
}

void loop() { 
  analogWrite(2,255);
  newposition = encoder49Pos;
  newangle = newposition*360/11.0;
  //Serial.println(newposition);
  newtime = millis();
  vel_degrees = (newangle - oldangle )*1000 / (newtime - oldtime);
  Serial.print("RPM: ");
 Serial.println(vel_degrees*0.166666);
  //Serial.print("rad/s: ");
  //omega = vel_degrees*3.1415/(180.0*40);
 // Serial.println(omega);
  oldangle=newangle;
  oldposition = newposition;
  oldtime = newtime;

  //Serial.println();
delay(100);

}

void doEncoder(){
  if (digitalRead(encoder0PinA) == digitalRead(encoder0PinB)) {
    encoder49Pos++;
  } else {
    encoder49Pos--;
  }
}


//// encoder event for the interrupt call
//void doEncoder() {
//  if (digitalRead(encoder0PinA) == HIGH) {
//    if (digitalRead(encoder0PinB) == LOW) {
//      encoder49Pos++;
//    } else {
//      encoder49Pos--;
//    }
//  } else {
//    if (digitalRead(encoder0PinB) == LOW) {
//      encoder49Pos--;
//    } else {
//      encoder49Pos++;
//    }
//  }
//}

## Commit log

2019-11-21 Changed direction in the project. Next is motor
2019-11-21 [MATTIA MATTIONI] last group's matherial
    [DCSscheme.fzz]
2019-11-21 useless files
    [DCSscheme.fzz]
2019-12-19 [components][low-pass] modelling and wiring has been almost done
2019-12-27 [Marco][Andrea] meet for first assembling and tests
    We figured out how to connect everything and the first control application: i.e. open looptracking of sinusoidal velocity
2019-12-27 Sum up of the previous working days: Figured out how to use motor pinout and PWM
    Squashed commits:
    Fri Dec 27 13:05:19 2019 +0100
    [Marco][Andrea] meet for first assembling and tests
    Fri Dec 20 23:54:53 2019 +0100
    [2019-12-20] today's meeting recap
    Fri Dec 20 23:12:48 2019 +0100
    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
2020-01-03 Test load
    In this script we read the voltage on the potenziometer and we use this voltage to supply the motor
2020-01-03 Amplifier and prob
    We read the outpuit voltage of the amplifier and the input current of the motor
2020-01-04 Squashed commit of the following:
    Author: andrea-1996
    Amplifier and prob
    Author: andrea-1996
    Test load
    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
2020-02-04 [Marco] Initialization of scripts and functions to set clock-wise and counter clock-wise motion. Added draft of script to estimate load torque.
2020-02-07 Utility motor + personal
2020-02-11 new current probe + tests
2020-02-14 [dynamic load torque estimator] stuck
2020-02-18 Moveing materials
